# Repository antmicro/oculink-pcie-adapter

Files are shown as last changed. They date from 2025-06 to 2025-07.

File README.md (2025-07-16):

# OCuLink to PCIe adapter
Copyright (c) 2025 [Antmicro](https://www.antmicro.com)





## Overview

This project includes PCB design files for an adapter card which break-routes a regular OCuLink x4 connector into x16 PCIe edge card slot.
This board was designed for use with Antmicro [Jetson Orin Baseboard OCuLink Expansion](https://github.com/antmicro/job-oculink-expansion).
Please inspect the schematics and verify the connection diagrams if you plan to use that board with any other OCuLink-compliant accessories.
The PCB design files were prepared in KiCad 9.x 

## Key features

- Supports 4x PCIe link via an OCuLink connector over an x16 card edge connector
- PCIe cards can be powered via USB-C Power Delivery, EPS-12V or Molex Nano-Fit connector
- Optional on-board PCIe clock generator for SRSI and SRNS clocking configurations
- Mechanical outline optimized for  dual slot PCIe cards

## Project structure

The main directory contains KiCad PCB project files and README. 
The remaining files are stored in the following directories:

-   `img` - contains graphics for this README

## Licensing

This project is published under the [Apache-2.0](LICENSE) license.

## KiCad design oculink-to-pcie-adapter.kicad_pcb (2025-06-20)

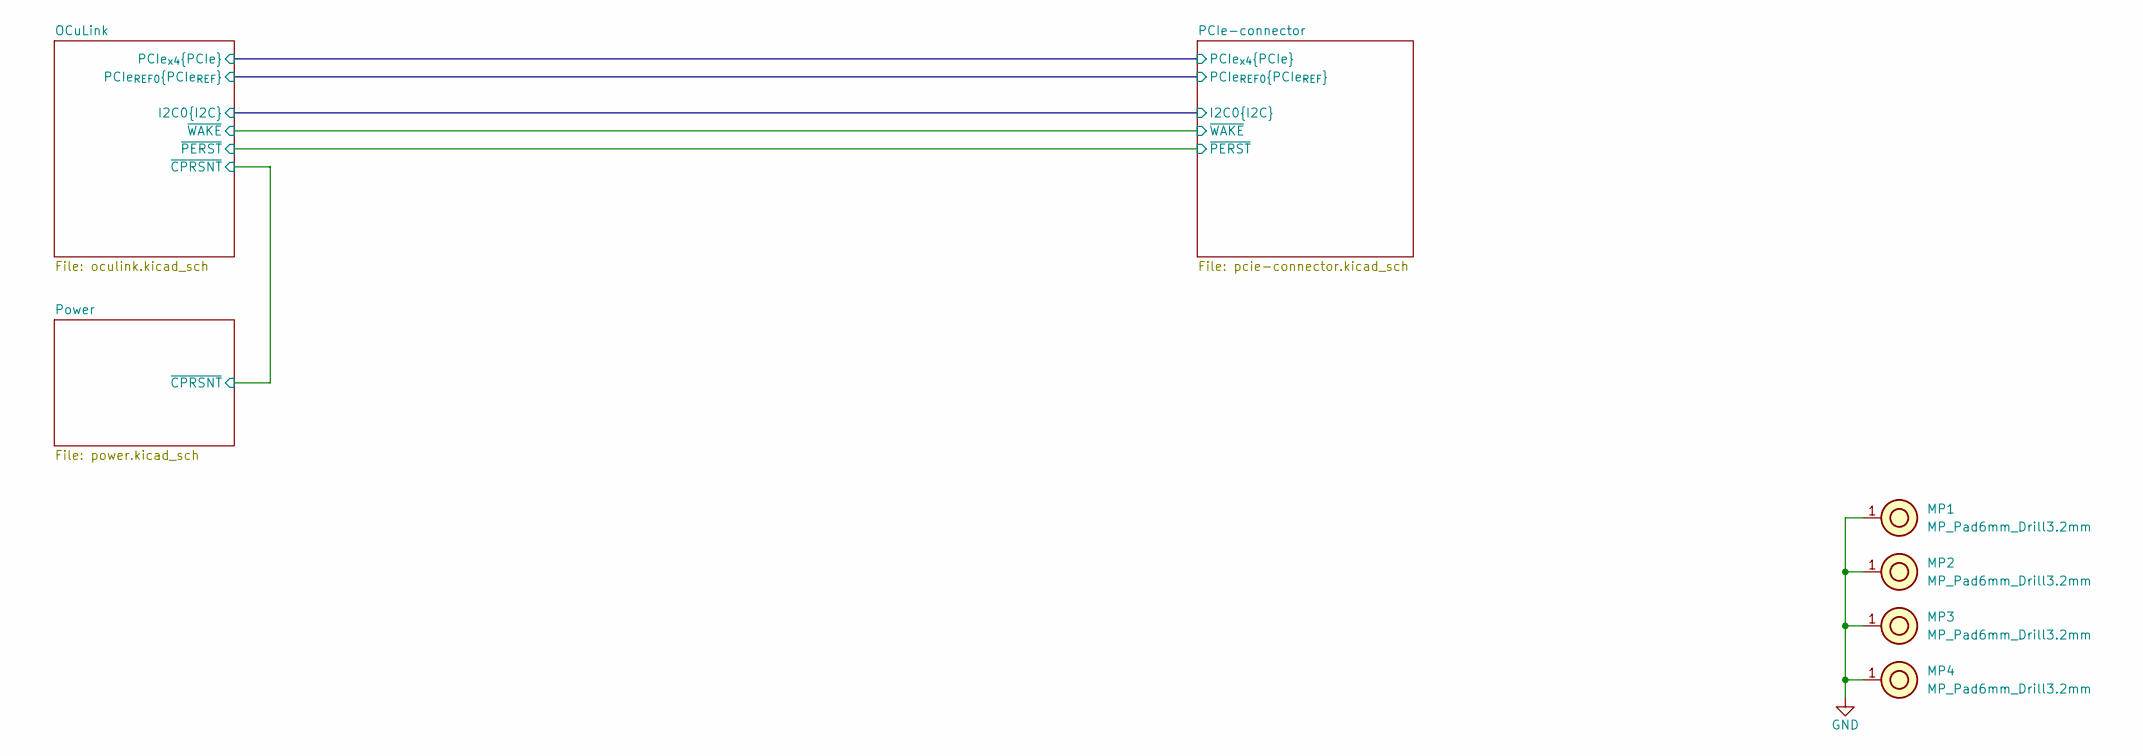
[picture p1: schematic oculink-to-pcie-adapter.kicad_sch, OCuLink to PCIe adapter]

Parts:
MP1, MP2, MP3, MP4: MP_Pad6mm_Drill3.2mm

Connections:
GND: MP1.1, MP2.1, MP3.1, MP4.1; also elsewhere on the board

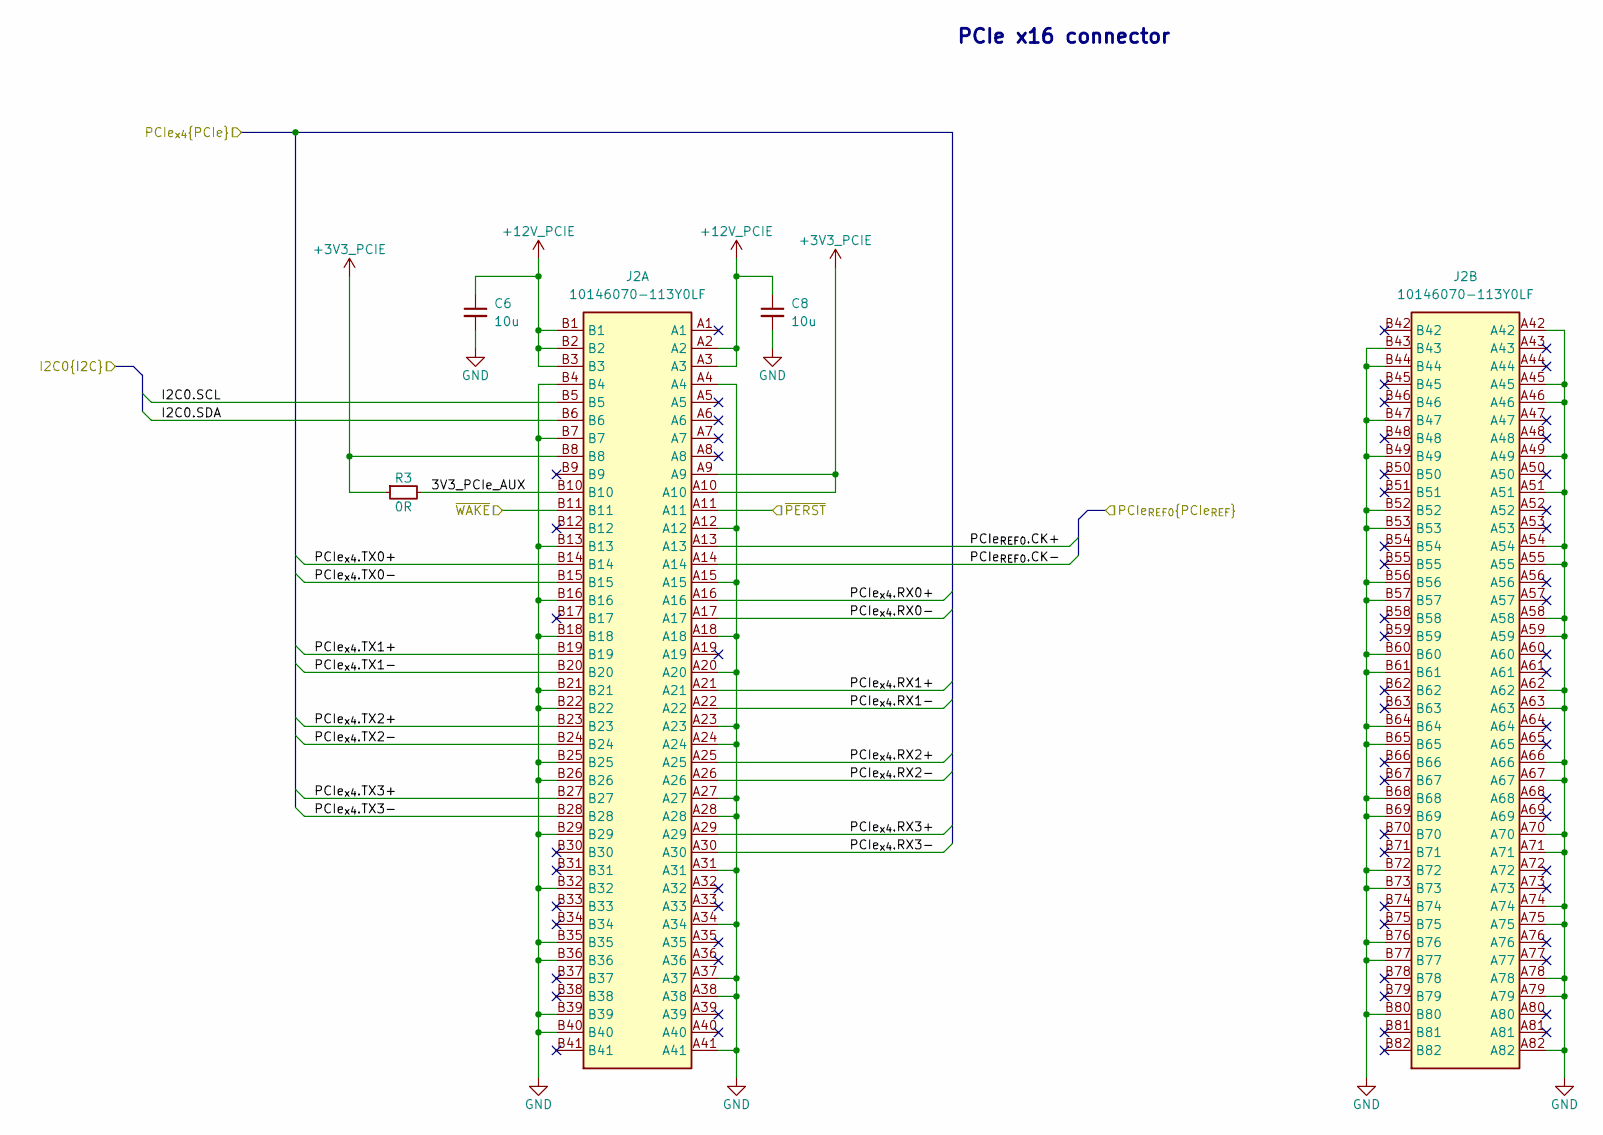
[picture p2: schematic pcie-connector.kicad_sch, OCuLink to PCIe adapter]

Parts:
C6, C8: C_10u_0805_35V; C_0805_2012Metric; Voltage 35V; MPN GRM21BR6YA106KE43L
J2: PCIe_x16_10146070-113Y0LF-vertical; AMPHENOL_10146070-113Y0LF; PARTREV E
R3: R_0R_0402; R_0402_1005Metric; MPN ERJ2GE0R00X

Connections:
+3V3_PCIE: J2.A9, J2.A10, J2.B8, R3.1; also elsewhere on the board
+12V_PCIE: C6.1, C8.1, J2.A2, J2.A3, J2.B1, J2.B2, J2.B3; also elsewhere on the board
/OCuLink/I2C0.SCL: J2.B5; also elsewhere on the board
/OCuLink/I2C0.SDA: J2.B6; also elsewhere on the board
/OCuLink/PCIe_{REF0}.CK+: J2.A13; also elsewhere on the board
/OCuLink/PCIe_{REF0}.CK-: J2.A14; also elsewhere on the board
/OCuLink/PCIe_{x4}.RX0+: J2.A16; also elsewhere on the board
/OCuLink/PCIe_{x4}.RX0-: J2.A17; also elsewhere on the board
/OCuLink/PCIe_{x4}.RX1+: J2.A21; also elsewhere on the board
/OCuLink/PCIe_{x4}.RX1-: J2.A22; also elsewhere on the board
/OCuLink/PCIe_{x4}.RX2+: J2.A25; also elsewhere on the board
/OCuLink/PCIe_{x4}.RX2-: J2.A26; also elsewhere on the board
/OCuLink/PCIe_{x4}.RX3+: J2.A29; also elsewhere on the board
/OCuLink/PCIe_{x4}.RX3-: J2.A30; also elsewhere on the board
/OCuLink/PCIe_{x4}.TX0+: J2.B14; also elsewhere on the board
/OCuLink/PCIe_{x4}.TX0-: J2.B15; also elsewhere on the board
/OCuLink/PCIe_{x4}.TX1+: J2.B19; also elsewhere on the board
/OCuLink/PCIe_{x4}.TX1-: J2.B20; also elsewhere on the board
/OCuLink/PCIe_{x4}.TX2+: J2.B23; also elsewhere on the board
/OCuLink/PCIe_{x4}.TX2-: J2.B24; also elsewhere on the board
/OCuLink/PCIe_{x4}.TX3+: J2.B27; also elsewhere on the board
/OCuLink/PCIe_{x4}.TX3-: J2.B28; also elsewhere on the board
/OCuLink/~PERST: J2.A11; also elsewhere on the board
/OCuLink/~WAKE: J2.B11; also elsewhere on the board
/PCIe-connector/3V3_PCIe_AUX: J2.B10, R3.2
GND: C6.2, C8.2, J2.A4, J2.A12, J2.A15, J2.A18, J2.A20, J2.A23, J2.A24, J2.A27, J2.A28, J2.A31, J2.A34, J2.A37, J2.A38, J2.A41, J2.A42, J2.A45, J2.A46, J2.A49, J2.A51, J2.A54, J2.A55, J2.A58, J2.A59, J2.A62, J2.A63, J2.A66, J2.A67, J2.A70, J2.A71, J2.A74, J2.A75, J2.A78, J2.A79, J2.A82, J2.B4, J2.B7, J2.B13, J2.B16, J2.B18, J2.B21, J2.B22, J2.B25, J2.B26, J2.B29, J2.B32, J2.B35, J2.B36, J2.B39, J2.B40, J2.B43, J2.B44, J2.B47, J2.B49, J2.B52, J2.B53, J2.B56, J2.B57, J2.B60, J2.B61, J2.B64, J2.B65, J2.B68, J2.B69, J2.B72, J2.B73, J2.B76, J2.B77, J2.B80; also elsewhere on the board

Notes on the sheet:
PCIe x16 connector

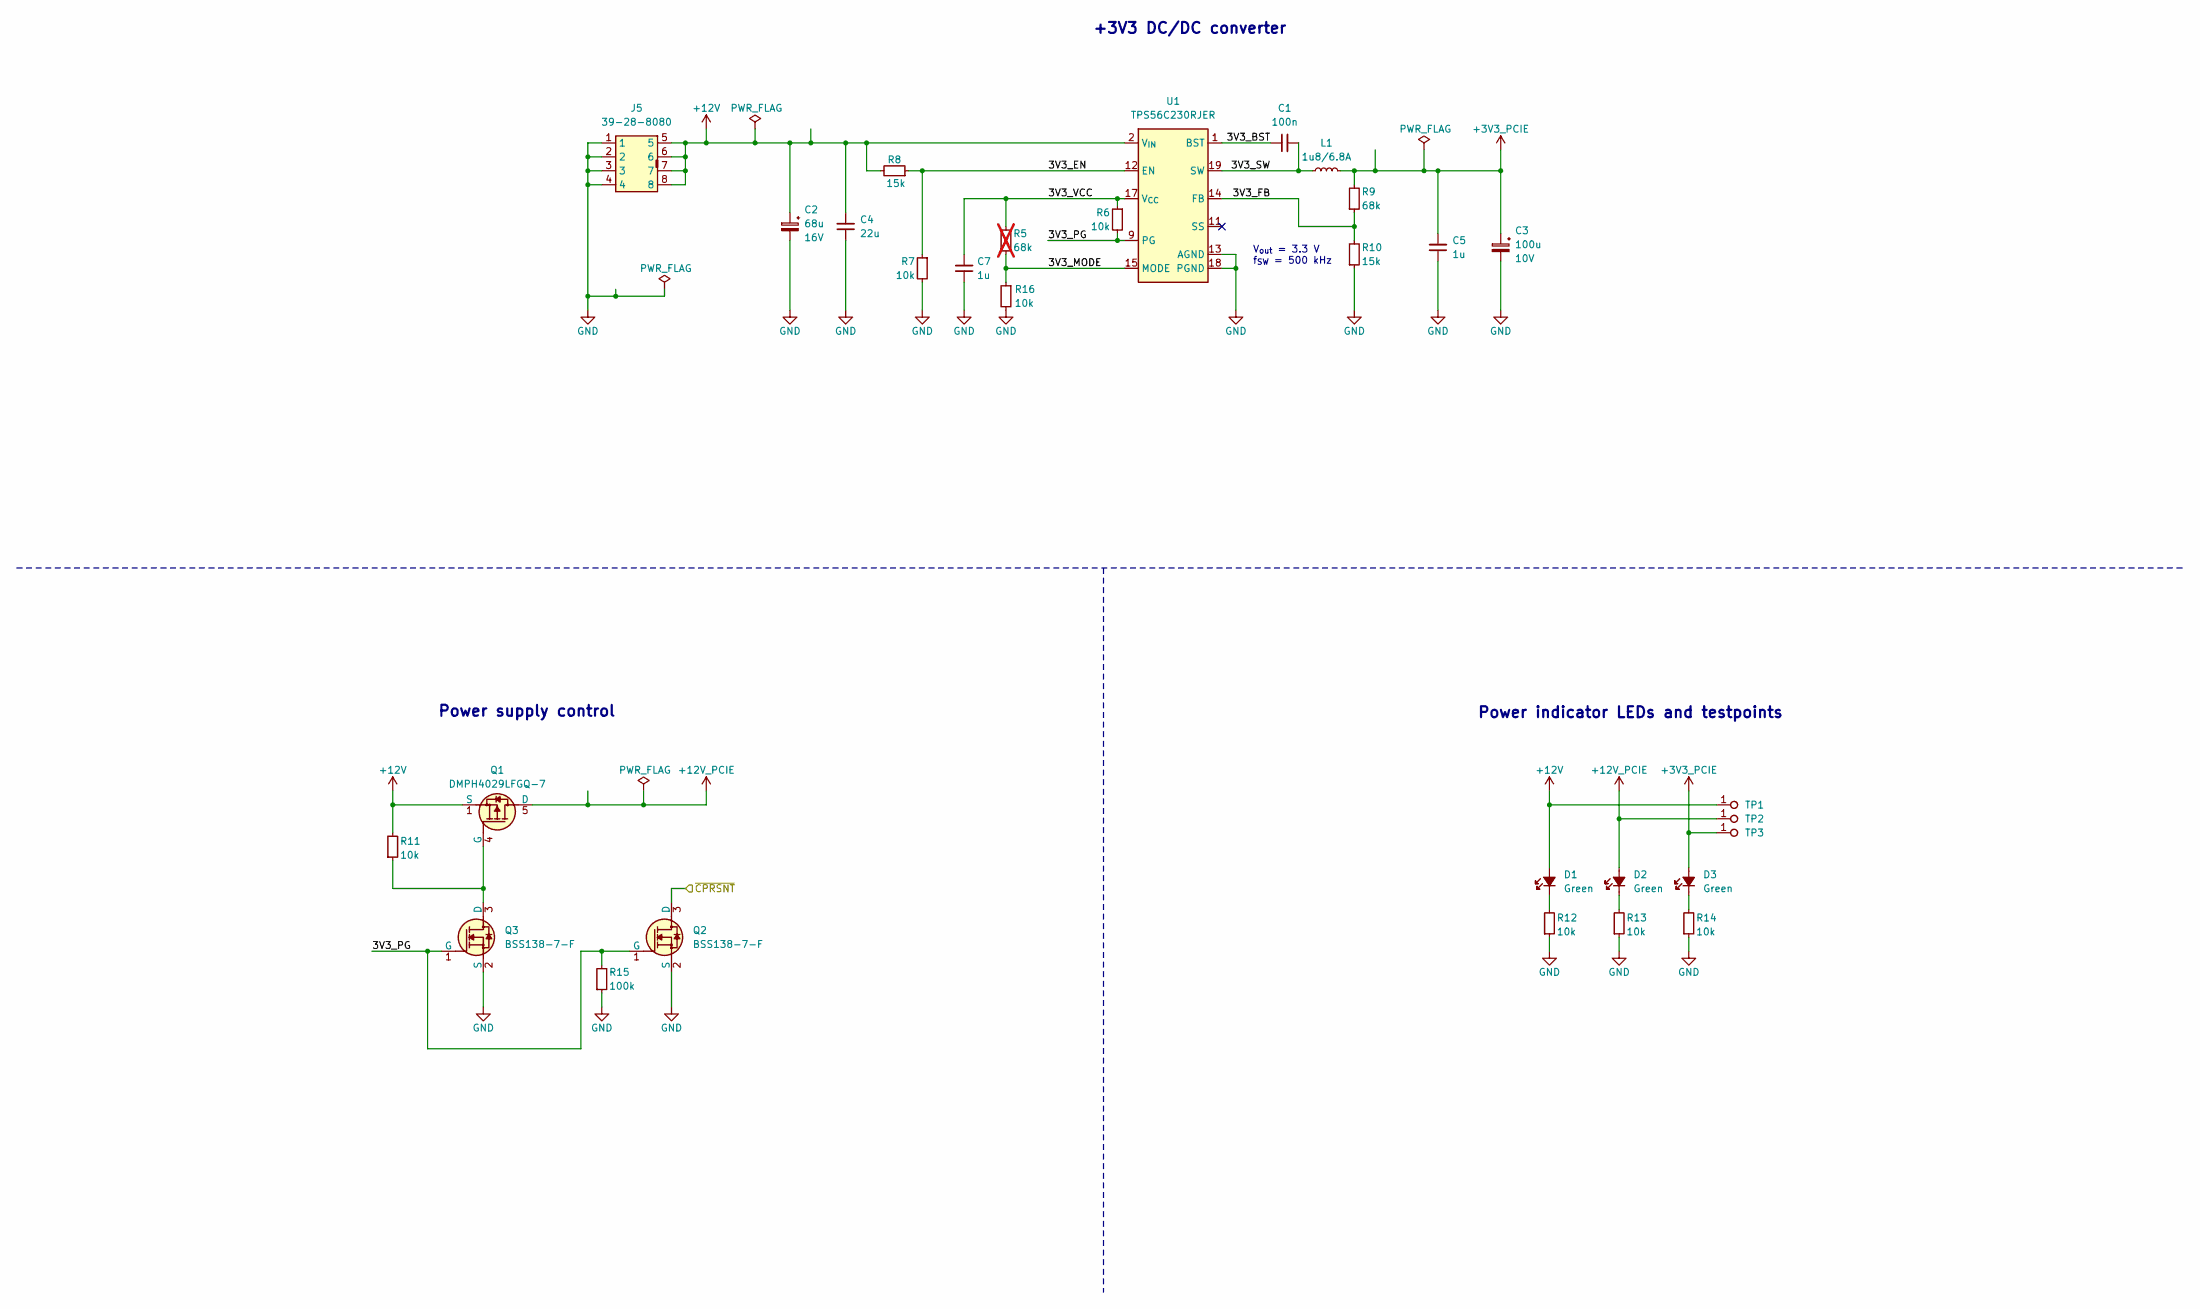
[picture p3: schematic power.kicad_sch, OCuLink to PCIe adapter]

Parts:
C1: C_100n_0402; C_0402_1005Metric; Voltage 50V; MPN GRM155R61H104KE14D
C2: C_Pol_68u_16V_Panasonic-TQC-D; C_Pol_EIA-D; Voltage 16V; MPN 16TQC68MYF
C3: C_Pol_100u_10V_KEMET-T520-B; C_Pol_EIA-B; Voltage 10V; MPN T520B107M010ATE070
C4: C_22u_16V_0603; C_0603_1608Metric_EIA; Voltage 16V; MPN CL10A226MO7JZNC
C5, C7: C_1u_0402; C_0402_1005Metric; MPN C1005X6S1A105K050BC
D1, D2, D3: LED_G_0603_LTST-C190GKT; LED_0603_1608Metric_G; MPN LTST-C190GKT
J5: Molex_Mini-Fit-Jr_2x4_39-28-8080; MOLEX_39288080; MPN 39-28-8080
L1: L_1u8_6.8A_WE-MAPI-4020; L_WE-MAPI-4020; MPN 74438356018
Q1: DMPH4029LFGQ; PowerDI3333-8; MPN DMPH4029LFGQ-7
Q2, Q3: BSS138-7-F; SOT-23-3; MPN BSS138-7-F
R5: R_68k_0402; R_0402_1005Metric; Tolerance 1%; MPN CR0402-FX-6802GLF; not fitted
R6, R7, R11, R12, R13, R14, R16: R_10k_0402; R_0402_1005Metric; Tolerance 1%; MPN CR0402-FX-1002GLF
R8, R10: R_15k_0402; R_0402_1005Metric; Tolerance 1%; MPN CR0402-FX-1502GLF
R9: R_68k_0402; R_0402_1005Metric; Tolerance 1%; MPN CR0402-FX-6802GLF
R15: R_100k_0402; R_0402_1005Metric; Tolerance 1%; MPN CR0402-FX-1003GLF
TP1, TP2, TP3: TP_0.75mm_SMD; TP_SMD_0.75mm
U1: TPS56C230; QFN-20-1EP_3x3mm_P0.45mm; MPN TPS56C230RJER

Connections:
+3V3_PCIE: C3.1, C5.2, D3.2 (A), L1.2, R9.2, TP3.1; also elsewhere on the board
+12V: C2.1, C4.2, D1.2 (A), J5.5, J5.6, J5.7, J5.8, Q1.1 (S), Q1.2 (S), Q1.3 (S), R8.2, R11.2, TP1.1, U1.2 (V_{IN}), U1.3 (V_{IN}), U1.4 (V_{IN}), U1.5 (V_{IN})
+12V_PCIE: D2.2 (A), Q1.5 (D), TP2.1; also elsewhere on the board
/OCuLink/~CPRSNT: Q2.3 (D); also elsewhere on the board
/Power/3V3_BST: C1.1, U1.1 (BST)
/Power/3V3_EN: R7.1, R8.1, U1.12 (EN)
/Power/3V3_FB: R9.1, R10.2, U1.14 (FB)
/Power/3V3_MODE: R5.1, R16.1, U1.15 (MODE)
/Power/3V3_PG: Q2.1 (G), Q3.1 (G), R6.2, R15.2, U1.9 (PG)
/Power/3V3_SW: C1.2, L1.1, U1.6 (SW), U1.19 (SW), U1.20 (SW)
/Power/3V3_VCC: C7.2, R5.2, R6.1, U1.17 (V_{CC})
GND: C2.2, C3.2, C4.1, C5.1, C7.1, J5.1, J5.2, J5.3, J5.4, Q2.2 (S), Q3.2 (S), R7.2, R10.1, R12.1, R13.1, R14.1, R15.1, R16.2, U1.7 (PGND), U1.8 (PGND), U1.13 (AGND), U1.18 (PGND), U1.21 (PGND); also elsewhere on the board
unnamed: D1.1 (C), R12.2
unnamed: D2.1 (C), R13.2
unnamed: D3.1 (C), R14.2
unnamed: Q1.4 (G), Q3.3 (D), R11.1

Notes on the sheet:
V_{out} = 3.3 V f_{SW} = 500 kHz
+3V3 DC/DC converter
Power indicator LEDs and testpoints
Power supply control

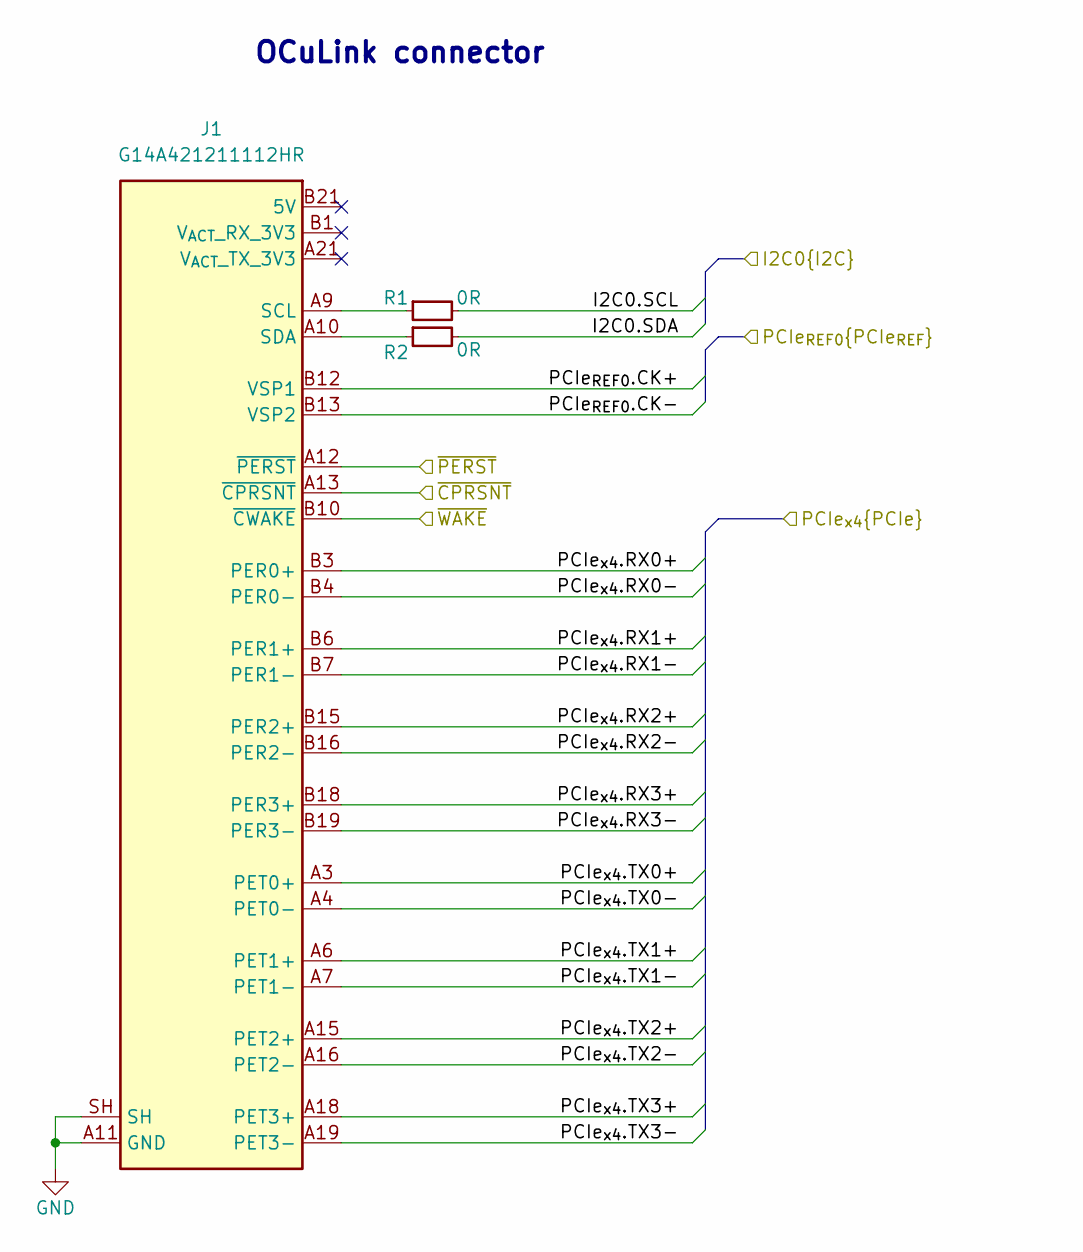
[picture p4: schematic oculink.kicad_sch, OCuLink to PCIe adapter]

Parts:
J1: OCuLink_x4_Amphenol_G14A421211112HR; Amphenol_G14A421211112HR; MPN G14A421211112HR
R1, R2: R_0R_0402; R_0402_1005Metric; MPN ERJ2GE0R00X

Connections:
/OCuLink/I2C0.SCL: R1.2; also elsewhere on the board
/OCuLink/I2C0.SDA: R2.2; also elsewhere on the board
/OCuLink/PCIe_{REF0}.CK+: J1.B12 (VSP1); also elsewhere on the board
/OCuLink/PCIe_{REF0}.CK-: J1.B13 (VSP2); also elsewhere on the board
/OCuLink/PCIe_{x4}.RX0+: J1.B3 (PER0+); also elsewhere on the board
/OCuLink/PCIe_{x4}.RX0-: J1.B4 (PER0-); also elsewhere on the board
/OCuLink/PCIe_{x4}.RX1+: J1.B6 (PER1+); also elsewhere on the board
/OCuLink/PCIe_{x4}.RX1-: J1.B7 (PER1-); also elsewhere on the board
/OCuLink/PCIe_{x4}.RX2+: J1.B15 (PER2+); also elsewhere on the board
/OCuLink/PCIe_{x4}.RX2-: J1.B16 (PER2-); also elsewhere on the board
/OCuLink/PCIe_{x4}.RX3+: J1.B18 (PER3+); also elsewhere on the board
/OCuLink/PCIe_{x4}.RX3-: J1.B19 (PER3-); also elsewhere on the board
/OCuLink/PCIe_{x4}.TX0+: J1.A3 (PET0+); also elsewhere on the board
/OCuLink/PCIe_{x4}.TX0-: J1.A4 (PET0-); also elsewhere on the board
/OCuLink/PCIe_{x4}.TX1+: J1.A6 (PET1+); also elsewhere on the board
/OCuLink/PCIe_{x4}.TX1-: J1.A7 (PET1-); also elsewhere on the board
/OCuLink/PCIe_{x4}.TX2+: J1.A15 (PET2+); also elsewhere on the board
/OCuLink/PCIe_{x4}.TX2-: J1.A16 (PET2-); also elsewhere on the board
/OCuLink/PCIe_{x4}.TX3+: J1.A18 (PET3+); also elsewhere on the board
/OCuLink/PCIe_{x4}.TX3-: J1.A19 (PET3-); also elsewhere on the board
/OCuLink/~CPRSNT: J1.A13 (~CPRSNT); also elsewhere on the board
/OCuLink/~PERST: J1.A12 (~PERST); also elsewhere on the board
/OCuLink/~WAKE: J1.B10 (~CWAKE); also elsewhere on the board
GND: J1.A2 (GND), J1.A5 (GND), J1.A8 (GND), J1.A11 (GND), J1.A14 (GND), J1.A17 (GND), J1.A20 (GND), J1.B2 (GND), J1.B5 (GND), J1.B8 (GND), J1.B11 (GND), J1.B14 (GND), J1.B17 (GND), J1.B20 (GND), J1.SH; also elsewhere on the board
unnamed: J1.A9 (SCL), R1.1
unnamed: J1.A10 (SDA), R2.1

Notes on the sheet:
OCuLink connector

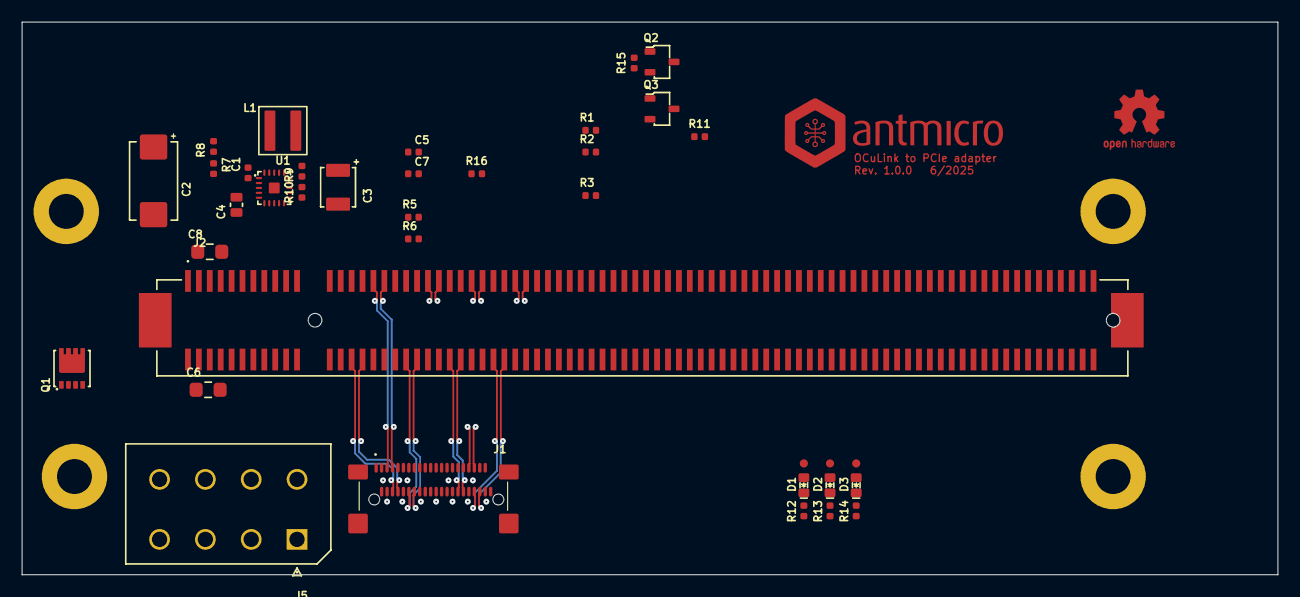
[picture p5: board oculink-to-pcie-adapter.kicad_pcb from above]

Board: 4 copper layers, 115.1 x 50.6 mm, 41 parts (0 on the bottom side), 41 nets.

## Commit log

2025-06-18 [#79026] Add gitignore, init project
    [oculink-to-pcie-adapter.kicad_pcb, oculink-to-pcie-adapter.kicad_sch]
2025-06-18 [#79026] Add OCuLink and PCIex16 connectors, connect them together
    [oculink-to-pcie-adapter.kicad_pcb, oculink-to-pcie-adapter.kicad_sch, oculink.kicad_sch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]
2025-06-18 [#79026] Add power supply section, reannotate schematic
    [oculink-to-pcie-adapter.kicad_sch, oculink.kicad_sch, pcie-connector.kicad_sch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]
2025-06-20 [#79026] Change power input connector, add net classes, minor schematic refactor
    [oculink.kicad_sch, pcie-connector.kicad_sch, power.kicad_sch]
2025-06-20 [#79262] Begin component placement, add 12V PCIe decoupling capacitors, reduce inductor size
    [oculink-to-pcie-adapter.kicad_pcb, oculink.kicad_sch, pcie-connector.kicad_sch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]
2025-06-20 [#79262] Define stackup and PCIe differential pair parameters, start layout
    [oculink-to-pcie-adapter.kicad_pcb, oculink.kicad_sch]
2025-06-20 [#79262] Add USB PD input, 12V DC-DC converter, power ORing
    [oculink-to-pcie-adapter.kicad_sch, oculink.kicad_sch, power.kicad_sch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]
2025-06-20 [#79262] Move ideal diodes and Molex connector to separate schematic sheet
    [ideal-diode.kicad_sch, molex-connector.kicad_sch, oculink-to-pcie-adapter.kicad_sch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]
2025-06-24 [#79262] Change TVS diodes, adjust LEDs resistors, refactor USB-PD schematic
    [pcie-connector.kicad_sch, power.kicad_sch, usb-pd.kicad_sch]
2025-06-24 [#79262] Cleanup 12V DC-DC converter, move Molex connector to root sheet
    [molex-connector.kicad_sch, oculink-to-pcie-adapter.kicad_sch, pcie-connector.kicad_sch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]
2025-06-24 [#79262] Finish power section schematic
    [ideal-diode.kicad_sch, oculink-to-pcie-adapter.kicad_sch, pcie-connector.kicad_sch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]
2025-06-24 [#79262] Add TVS to OCuLink connector, add decoupling capacitors for PCIe connector
    [oculink.kicad_sch, pcie-connector.kicad_sch]
2025-06-24 [#79262] BOM consolidation
    [ideal-diode.kicad_sch, power.kicad_sch, usb-pd.kicad_sch]
2025-06-24 [#79262] Add TVS to 12V power pins
    [pcie-connector.kicad_sch, power.kicad_sch]
2025-06-24 [#79262] Further BOM consolidation
    [ideal-diode.kicad_sch, oculink.kicad_sch, power.kicad_sch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]
2025-06-25 [#79262] Remove 12V DC-DC R_boot resistor
    [usb-pd.kicad_sch]
2025-06-25 [#79262] Reduce Q4 max Vgs
    [power.kicad_sch, usb-pd.kicad_sch]
2025-06-25 [#79262] Perform component placement of 12V DC-DC converter, USB PD section and ideal diodes
2025-06-25 [#79262] Fix directions of hierarchical labels
    [oculink-to-pcie-adapter.kicad_sch, oculink.kicad_sch, pcie-connector.kicad_sch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]
2025-06-25 [#79262] Change USB PD controller to CYPD3177
    [usb-pd.kicad_sch]
2025-06-27 [#79426] Small USB-PD improvements
    [oculink.kicad_sch, usb-pd.kicad_sch]
2025-06-27 [#79426] Removed power sequencing, added PERST control
    [oculink-to-pcie-adapter.kicad_sch, oculink.kicad_sch, pcie-connector.kicad_sch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]
2025-06-27 [#79426] Add PCIe power connector
    [oculink-to-pcie-adapter.kicad_sch, oculink.kicad_sch, usb-pd.kicad_sch]
2025-06-27 [#79426] Add optional clock generator
    [oculink-to-pcie-adapter.kicad_sch, oculink.kicad_sch, pcie-clock-generator.kicad_sch]
2025-06-27 [#79426] Minor USB-C PD schematic fixes
    [usb-pd.kicad_sch]
2025-06-27 [#79426] Connect DC input connectors via ideal diodes, change 15V TVS to 12V TVS
    [ideal-diode.kicad_sch, oculink-to-pcie-adapter.kicad_sch, power.kicad_sch]
2025-06-27 [#79426] Fix USB-PD fault LED to prevent excessive MOSFET Vgs
    [usb-pd.kicad_sch]
2025-06-27 [#79426] Change Q3 MOSFET
    [power.kicad_sch]
2025-06-27 [#79426] Add 0R to OCuLink control signals
    [oculink.kicad_sch]
2025-06-27 [#79426] Change 3V3 DC-DC UVLO to 11.3V
    [power.kicad_sch]
2025-06-27 [#79262] WIP: Component placement
    [oculink.kicad_sch, pcie-clock-generator.kicad_sch]
2025-06-30 [#79262] Adjusted placement
    [oculink-to-pcie-adapter.kicad_sch, oculink.kicad_sch, pcie-clock-generator.kicad_sch]
2025-06-30 [#79262] Rotated the board files
2025-07-01 [#79262] Route high speed and power
    [oculink.kicad_sch, pcie-clock-generator.kicad_sch, pcie-connector.kicad_sch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]
2025-07-02 [#79262] Connect all the signals
    [oculink.kicad_sch, pcie-clock-generator.kicad_sch, usb-pd.kicad_sch]
2025-07-02 [#79262] Place silkscreen
2025-07-02 [#79262] DRC clean
    [oculink.kicad_sch, pcie-clock-generator.kicad_sch, pcie-connector.kicad_sch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]
2025-07-02 [#79262] Add PCB SHA
2025-07-07 [#79790] Made board smaller, moved connectors to shorter edge
    [oculink-to-pcie-adapter.kicad_sch, oculink.kicad_sch, pcie-clock-generator.kicad_sch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]
2025-07-08 [#79790] Finalized rerouting
    [oculink-to-pcie-adapter.kicad_sch, oculink.kicad_sch, pcie-clock-generator.kicad_sch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]
2025-07-08 [#79790] Slight silkscreen improvements
2025-07-08 [#79790] Reduced board size to integer amount of mm
2025-07-08 Updated render image and schematic pdf
2025-07-09 [#79790] Added fiducials and double sided test points
    [oculink.kicad_sch, pcie-clock-generator.kicad_sch, power.kicad_sch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]
2025-07-09 Update schematic pdf and README image
2025-07-11 [#79790] Applied review fixes
    [oculink.kicad_sch, pcie-clock-generator.kicad_sch, pcie-connector.kicad_sch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]
2025-07-11 [#79790] Fixed pinout of OCuLink
    [oculink.kicad_sch, pcie-clock-generator.kicad_sch, usb-pd.kicad_sch]

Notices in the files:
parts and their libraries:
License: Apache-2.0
